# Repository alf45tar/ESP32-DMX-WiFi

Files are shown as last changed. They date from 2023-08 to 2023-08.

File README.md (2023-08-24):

# ESP32-DMX-WiFi

Art-Net to DMX gateway and viceversa. It supports RDM and sACN (E1.31) too.

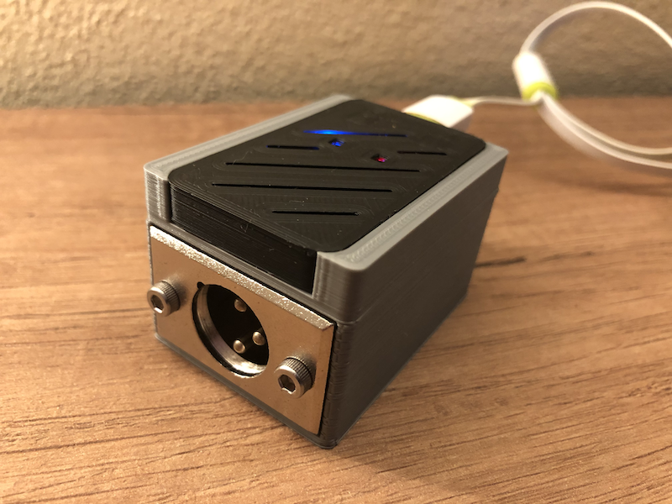
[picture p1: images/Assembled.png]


Strongly based on amazing [LXDMXWiFi_Library](https://github.com/claudeheintz/LXDMXWiFi_Library) example [ESP32-DMX_rdm](https://github.com/claudeheintz/LXDMXWiFi_Library/tree/master/examples/ESP32-DMX_rdm).

Configuration utility for macOS and Windows is [here](https://github.com/claudeheintz/LXDMXWiFi_Library/tree/master/examples/configuration%20utility)

Changes from original source are:
```
#define STARTUP_MODE_PIN       0    // use onboard built-in button for force default setup
#define DIRECTION_PIN          4    // pin for output direction enable on RS-485 transceiver chip
#define DMXSERIAL_INPUT_PIN   16    // default UART2 RX pin
#define DMXSERIAL_OUTPUT_PIN  17    // default UART2 TX pin
#define STATUS_LED             2    // LED_BUILTIN for DOIT ESP32 DevKit V1

....

#define USE_REMOTE_CONFIG      0    // uncommented line for enable the configuration utility
```

## Bill of materials

- DOIT ESP32 DevKit V1 30 pins board
- RS-485 transceiver like SN75176 or MAX485 or equivalent
- Male XLR panel mount connector
- 2x M3 x 8 mm bolts
- 2x M3 nuts
- 1K Ohm 1/4 watt resistor
- 2K Ohm 1/4 watt resistor

## Schematic

```

RX2/GPIO16  ---+
               |                       
          2k   |   1k    +---------------+
GND  ---/\/\/\-+-/\/\/\--| R         VCC |---------- +5V (VIN when ESP32 board is powered by USB)
                         |               |
                    +----| RE/         B |---------- Data - (XLR pin 2)
                    |    |    SN75176    |
GPIO04      --------+----| DE          A |---------- Data + (XLR pin 3)
                         |               |
TX2/GPIO17  -------------| D         GND |---+------ Ground (XLR pin 1)
                         +---------------+   |
                                             |
                                            GND
```

## Images

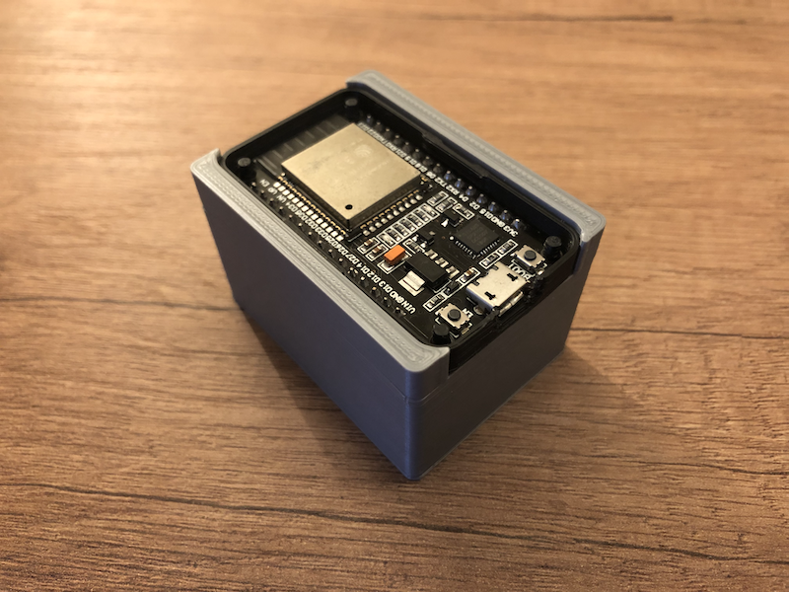
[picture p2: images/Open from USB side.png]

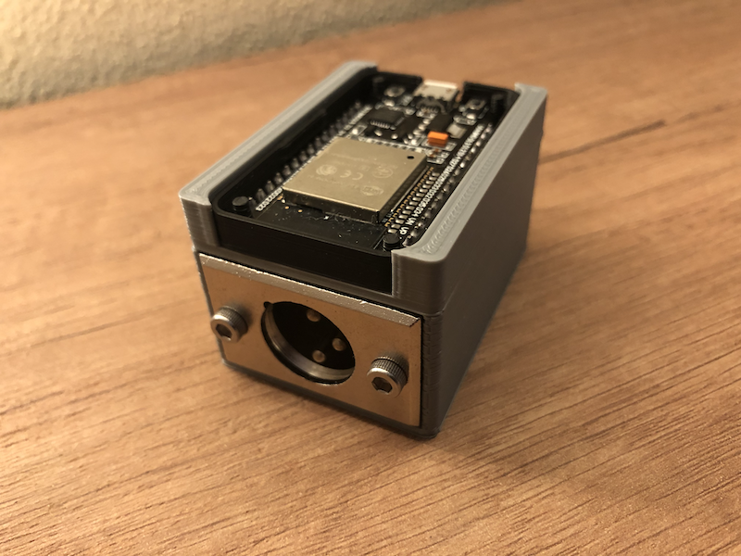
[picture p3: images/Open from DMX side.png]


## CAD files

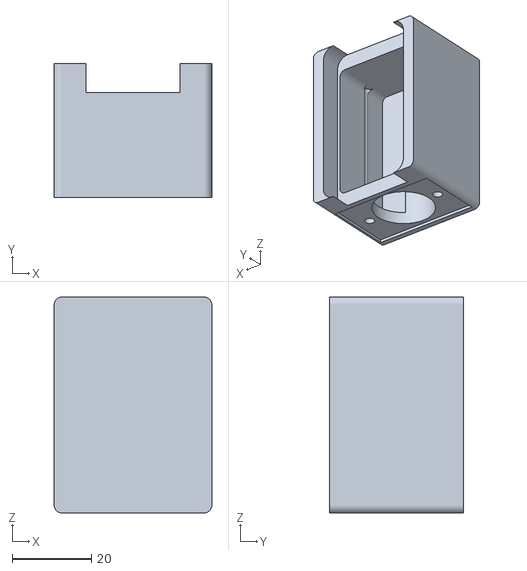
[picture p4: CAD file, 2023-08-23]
DMX Enclosure.stl
39.8 x 33.8 x 54.5

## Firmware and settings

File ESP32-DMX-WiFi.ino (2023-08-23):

/**************************************************************************/
/*
    @file     ESP32-DMX.ino
    @author   Claude Heintz
    @license  BSD (see LXDMXWiFi.h)
    @copyright 2017-2018 by Claude Heintz All Rights Reserved

    Example using LXDMXWiFi_Library for output of Art-Net or E1.31 sACN from
    ESP32 WiFi connection to serial DMX.  Or, input from DMX to the network.
    Allows remote configuration of WiFi connection and protocol settings.

    Art-Net(TM) Designed by and Copyright Artistic Licence Holdings Ltd.
    sACN E 1.31 is a public standard published by the PLASA technical standards program

    Note:  This example requires the LXESP32DMX library for DMX serial output
           https://github.com/claudeheintz/LXESP32DMX

    @section  HISTORY

    v1.0 - First release
    v1.1 - Improve multi-task compatibility
    v1.2 - Modified for Adafruit ESP-32 Feather
    v1.3 - adds ArtPoll response in input mode
	v1.4 - add variable tx/rx pin assignments

*/
/**************************************************************************/

#include <LXESP32DMX.h>
#include <UID.h>
#include <TOD.h>
#include <rdm_utility.h>
#include <WiFi.h>
#include <WiFiUdp.h>
#include "LXDMXWiFi.h"
#include <LXWiFiArtNet.h>
#include <LXWiFiSACN.h>
#include "LXDMXWiFiConfig.h"
#include "freertos/task.h"


#define STARTUP_MODE_PIN       0    // pin for force default setup when low (use 10k pullup to insure high)

#define DIRECTION_PIN			     4		// pin for output direction enable on MAX481 chip
#define DMXSERIAL_INPUT_PIN		16		// default UART2 RX pin
#define DMXSERIAL_OUTPUT_PIN	17		// default UART2 TX pin
#define STATUS_LED             2    // LED_BUILTIN for DOIT ESP32 DevKit V1

#define DEBUG_PIN_A 22
#define DEBUG_PIN_B 23
#define DEBUG_PIN_C 15

char ssid[32];
char password[32];

// RDM defines
#define DISC_STATE_SEARCH 0
#define DISC_STATE_TBL_CK 1
/*
   If RDM_DISCOVER_ALWAYS == 0, the times RDM discovery runs is limited to 10 cycles
   of table check and search.  When rdm_discovery_enable reaches zero, continous RDM
   discovery stops.  Other ArtRDM packets continue to be relayed.
   If an Art-Net TODRequest or TODControl packet is received, the rdm_discovery_enable
   counter is reset and discovery runs again until rdm_discovery_enable reaches zero.
*/
#define RDM_DISCOVER_ALWAYS 0

/*         
 *  To allow use of the configuration utility, uncomment the following to define USE_REMOTE_CONFIG
 *  When using remote configuration:
 *        The remote configuration utility can be used to edit the settings without re-loading the sketch.
 *        Settings from persistent memory are used unless the startup pin is read LOW.
 *        Holding the startup pin low temporarily uses the settings in the LXDMXWiFiConfig.initConfig() method.
 *        This insures there is a default way of connecting to the sketch in order to use the remote utility,
 *        even if it is configured to use a WiFi network that is unavailable.
 *
 *	Without remote configuration (USE_REMOTE_CONFIG remains undefined), settings are read from the 
 *  LXDMXWiFiConfig.initConfig() method.  So, it is necessary to edit that function in order to change
 *  the settings.
 */
 #define USE_REMOTE_CONFIG 0

// dmx protocol interfaces for parsing packets (created in setup)
LXWiFiArtNet* artNetInterface;
LXWiFiSACN*   sACNInterface;

// EthernetUDP instances to let us send and receive UDP packets
WiFiUDP aUDP;
WiFiUDP sUDP;

// the following appear to be ESP32's default AP address/subnet mask
// required to specify as WiFi.localIP() returns 0.0.0.0 when in AP mode and must use softAPIP() instead
IPAddress local_ip_address = IPAddress(192,168,4,1);
IPAddress local_subnet_mask = IPAddress(255,255,255,0);

// direction output from network/input to network
uint8_t dmx_direction = 0;

// Output mode: received packet contained dmx
int art_packet_result = 0;
int acn_packet_result = 0;

// Input mode:  received slots when inputting dmx to network
int got_dmx = 0;

// RDM globals
uint8_t rdm_enabled = 0;                      // global RDM flag
uint8_t rdm_discovery_enable = 10;            // limit RDM discovery which can cause flicker in some equipment
uint8_t discovery_state = DISC_STATE_TBL_CK;  // alternates between checking the TOD and discovery search
uint8_t discovery_tbl_ck_index = 0;           // next entry in table to check by sending DISC_MUTE
uint8_t tableChangedFlag = 0;                 // set when TOD is changed by device added or removed
uint8_t idle_count = 0;                       // count to determine cycles devoted to RDM discovery
TOD tableOfDevices;                           // UUIDs of found devices
TOD discoveryTree;                            // stack of UUID ranges for discovery search

UID lower(0, 0, 0, 0, 0, 0);
UID upper(0, 0, 0, 0, 0, 0);
UID mid(0, 0, 0, 0, 0, 0);
UID found(0, 0, 0, 0, 0, 0);

// used to toggle indicator LED on and off
uint8_t led_state = 0;

/*
   utility function to toggle indicator LED on/off
*/
void blinkLED() {
  if ( led_state ) {
    digitalWrite(STATUS_LED, HIGH);
    led_state = 0;
  } else {
    digitalWrite(STATUS_LED, LOW);
    led_state = 1;
  }
}

/*
   artAddress callback allows storing of config information
   artAddress may or may not have set this information
   but relevant fields are copied to config struct and stored to EEPROM
*/
void artAddressReceived() {
  DMXWiFiConfig.setArtNetPortAddress( artNetInterface->universe() );
  DMXWiFiConfig.setNodeName( artNetInterface->longName() );
  DMXWiFiConfig.commitToPersistentStore();
}

void artTodRequestReceived(uint8_t* pdata) {
  rdm_discovery_enable = 10;
  artNetInterface->send_art_tod(&aUDP, tableOfDevices.rawBytes(), tableOfDevices.count());
}

void artRDMReceived(uint8_t* pdata) {
  uint8_t plen = pdata[1] + 2;
  uint8_t j;

  //copy into ESP32DMX outgoing packet
  uint8_t* pkt = ESP32DMX.rdmData();
  for (j = 0; j < plen; j++) {
    pkt[j + 1] = pdata[j];
  }
  pkt[0] = 0xCC;


  if ( ESP32DMX.sendRDMControllerPacket() ) {
    artNetInterface->send_art_rdm(&aUDP, ESP32DMX.receivedRDMData(), aUDP.remoteIP());
  }
}

/*
   artIpProg callback allows storing of config information
   cmd field bit 7 indicates that settings should be programmed
*/
void artIpProgReceived(uint8_t cmd, IPAddress addr, IPAddress subnet) {
  if ( cmd & 0x80 ) {
    if ( cmd & 0x40 ) {	//enable dhcp, other fields not written
      if ( DMXWiFiConfig.staticIPAddress() ) {
        DMXWiFiConfig.setStaticIPAddress(0);
      } else {
        return;	// already set to dhcp
      }
    } else {
      if ( ! DMXWiFiConfig.staticIPAddress() ) {
        DMXWiFiConfig.setStaticIPAddress(1);	// static not dhcp
      }
      if ( cmd & 0x08 ) {	//factory reset
        DMXWiFiConfig.initConfig();
      } else {
        if ( cmd & 0x04 ) {	//programIP
          DMXWiFiConfig.setStationIPAddress(addr);
        }
        if ( cmd & 0x02 ) {	//programSubnet
          DMXWiFiConfig.setStationSubnetMask(subnet);
        }
      }
    }	// else ( ! dhcp )

    DMXWiFiConfig.commitToPersistentStore();
  }
}

/*
  Indicator was requested by ArtAddress packet
*/
void artIndicatorReceived(bool normal, bool mute, bool locate) {
    if (normal) {
        Serial.println("Normal mode");
    } else if (mute) {
        Serial.println("Mute mode");
    } else if (locate) {
        Serial.println("Locate mode");
    }
}

/*
  DMX input callback function sets number of slots received by ESP32DMX
*/

void gotDMXCallback(int slots) {
  got_dmx = slots;
}

/************************************************************************/

uint8_t testMute(UID u) {
  // try three times to get response when sending a mute message
  if ( ESP32DMX.sendRDMDiscoveryMute(u, RDM_DISC_MUTE) ) {
    return 1;
  }
  if ( ESP32DMX.sendRDMDiscoveryMute(u, RDM_DISC_MUTE) ) {
    return 1;
  }
  if ( ESP32DMX.sendRDMDiscoveryMute(u, RDM_DISC_MUTE) ) {
    return 1;
  }
  return 0;
}

void checkDeviceFound(UID found) {
  if ( testMute(found) ) {
    tableOfDevices.add(found);
    tableChangedFlag = 1;
  }
}

uint8_t checkTable(uint8_t ck_index) {
  if ( ck_index == 0 ) {
    ESP32DMX.sendRDMDiscoveryMute(BROADCAST_ALL_DEVICES_ID, RDM_DISC_UNMUTE);
  }

  if ( tableOfDevices.getUIDAt(ck_index, &found) )  {
    if ( testMute(found) ) {
      // device confirmed
      return ck_index += 6;
    }

    // device not found
    tableOfDevices.removeUIDAt(ck_index);
    tableChangedFlag = 1;
    return ck_index;
  }
  // index invalid
  return 0;
}

//called when range responded, so divide into sub ranges push them on stack to be further checked
void pushActiveBranch(UID lower, UID upper) {
  if ( mid.becomeMidpoint(lower, upper) ) {
    discoveryTree.push(lower);
    discoveryTree.push(mid);
    discoveryTree.push(mid);
    discoveryTree.push(upper);
  } else {
    // No midpoint possible:  lower and upper are equal or a 1 apart
    checkDeviceFound(lower);
    checkDeviceFound(upper);
  }
}

void pushInitialBranch() {
  lower.setBytes(0);
  upper.setBytes(BROADCAST_ALL_DEVICES_ID);
  discoveryTree.push(lower);
  discoveryTree.push(upper);

  //ETC devices seem to only respond with wildcard or exact manufacturer ID
  lower.setBytes(0x657400000000);
  upper.setBytes(0x6574FFFFFFFF);
  discoveryTree.push(lower);
  discoveryTree.push(upper);
}

uint8_t checkNextRange() {
  if ( discoveryTree.pop(&upper) ) {
    if ( discoveryTree.pop(&lower) ) {
      if ( lower == upper ) {
        checkDeviceFound(lower);
      } else {        //not leaf so, check range lower->upper
        uint8_t result = ESP32DMX.sendRDMDiscoveryPacket(lower, upper, &found);
        if ( result ) {
          //this range responded, so divide into sub ranges push them on stack to be further checked
          pushActiveBranch(lower, upper);

        } else if ( ESP32DMX.sendRDMDiscoveryPacket(lower, upper, &found) ) {
          pushActiveBranch(lower, upper); //if discovery fails, try a second time
        }
      }         // end check range
      return 1; // UID ranges may be remaining to test
    }           // end valid pop
  }             // end valid pop
  return 0;     // none left to pop
}

void sendTODifChanged() {
  if ( tableChangedFlag ) {   //if the table has changed...
    tableChangedFlag--;

    artNetInterface->send_art_tod(&aUDP, tableOfDevices.rawBytes(), tableOfDevices.count());

    Serial.println("_______________ Table Of Devices _______________");
    tableOfDevices.printTOD();
  }
}

void updateRDMDiscovery() {
  if ( rdm_discovery_enable ) {  // run RDM updates for a limited number of times
    if ( discovery_state ) {
      // check the table of devices
      discovery_tbl_ck_index = checkTable(discovery_tbl_ck_index);

      if ( discovery_tbl_ck_index == 0 ) {
        // done with table check
        discovery_state = DISC_STATE_SEARCH;
        pushInitialBranch();

        sendTODifChanged();
      } //end table check ended
    } else {    // search for devices in range popped from discoveryTree

      if ( checkNextRange() == 0 ) {
        // done with search
        discovery_tbl_ck_index = 0;
        discovery_state = DISC_STATE_TBL_CK;

        sendTODifChanged();
        if ( RDM_DISCOVER_ALWAYS == 0 ) {
          rdm_discovery_enable--;
        }
      }
    }           //end search
  }             // discovery enabled
}
/************************************************************************

  Setup creates the WiFi connection.

  It also creates the network protocol object,
  either an instance of LXWiFiArtNet or LXWiFiSACN.

  if OUTPUT_FROM_NETWORK_MODE:
     Starts listening on the appropriate UDP port.

     And, it starts the ESP32DMX sending serial DMX via the UART1 TX pin.
     (see the LXESP32DMX library documentation for driver details)

   if INPUT_TO_NETWORK_MODE:
     Starts ESP32DMX listening for DMX ( received as serial on UART0 RX pin. )

*************************************************************************/

void setup() {
  Serial.begin(115200);
  //Serial.setDebugOutput(1); //use uart0 for debugging
  pinMode(STATUS_LED, OUTPUT);
  pinMode(STARTUP_MODE_PIN, INPUT_PULLUP);
  pinMode(DIRECTION_PIN, OUTPUT);
  
  //debugging
  pinMode(DEBUG_PIN_A, OUTPUT);
  pinMode(DEBUG_PIN_B, OUTPUT);
  pinMode(DEBUG_PIN_C, OUTPUT);

  uint8_t bootStatus = DMXWiFiConfig.begin(1);//aparently need to read from persistent to be able to write to it
  uint8_t dhcpStatus = 0;                     //hence, read in begin and replace below if startup pin is low

#ifdef USE_REMOTE_CONFIG
  if ( digitalRead(STARTUP_MODE_PIN) == 0 ) {
#else
  if ( true ) {
#endif
    DMXWiFiConfig.initConfig();
    Serial.println("default startup config ");
  } else {
    Serial.println("using stored config ");
  }

  dmx_direction = DMXWiFiConfig.inputToNetworkMode();
  rdm_enabled   = DMXWiFiConfig.rdmMode();

  if ( DMXWiFiConfig.APMode() ) {            // WiFi startup
    Serial.print("AP_MODE ");
    Serial.print(DMXWiFiConfig.SSID());
    WiFi.mode(WIFI_AP);
    WiFi.softAP(DMXWiFiConfig.SSID());
    

    if ( digitalRead(STARTUP_MODE_PIN) != 0 ) { 
      WiFi.softAPConfig(DMXWiFiConfig.apIPAddress(), DMXWiFiConfig.apGateway(), DMXWiFiConfig.apSubnet());
      local_subnet_mask = DMXWiFiConfig.apSubnet();
    } else {
      Serial.print(" default AP settings ");
      Serial.println(DMXWiFiConfig.nodeName());
    };

    local_ip_address = WiFi.softAPIP();

    Serial.print(" accessPoint SSID ");
    Serial.print(DMXWiFiConfig.SSID());

    Serial.print(", ");
  } else {
    Serial.print("wifi connecting to ");
    Serial.print(DMXWiFiConfig.SSID());
    Serial.print("... ");
    WiFi.mode(WIFI_STA);
    strcpy(ssid, DMXWiFiConfig.SSID());
    strcpy(password, DMXWiFiConfig.password());
    WiFi.begin((const char*)ssid, (const char*)password);

    // static IP otherwise uses DHCP
    if ( DMXWiFiConfig.staticIPAddress() ) {
      Serial.print("static IP");
      WiFi.config(DMXWiFiConfig.stationIPAddress(), DMXWiFiConfig.stationGateway(), DMXWiFiConfig.stationSubnet());
    } else {
      dhcpStatus = 1;
    }

    while (WiFi.status() != WL_CONNECTED)  {
      delay(100);
      blinkLED();
    }

    local_ip_address = WiFi.localIP();
    local_subnet_mask = WiFi.subnetMask();
  }
  Serial.print("wifi started: ");
  Serial.println(local_ip_address);

  //------------------- Initialize serialDMX  -------------------

  if ( dmx_direction == OUTPUT_FROM_NETWORK_MODE ) {                // DMX Driver startup based on direction flag
    Serial.println("starting DMX");
    ESP32DMX.startRDM(DIRECTION_PIN, DMXSERIAL_INPUT_PIN, DMXSERIAL_OUTPUT_PIN);
  } else {
    Serial.println("starting DMX input");
    ESP32DMX.setDirectionPin(DIRECTION_PIN);
    ESP32DMX.setDataReceivedCallback(&gotDMXCallback);
    ESP32DMX.startInput(DMXSERIAL_INPUT_PIN);
  }

  //------------------- Initialize network<->DMX interfaces -------------------

  sACNInterface = new LXWiFiSACN();
  sACNInterface->setUniverse(DMXWiFiConfig.sACNUniverse());

  artNetInterface = new LXWiFiArtNet(local_ip_address, local_subnet_mask);
  artNetInterface->setUniverse(DMXWiFiConfig.artnetPortAddress());	//setUniverse for LXArtNet class sets complete Port-Address
  artNetInterface->setArtAddressReceivedCallback(&artAddressReceived);
  artNetInterface->setArtIpProgReceivedCallback(&artIpProgReceived);
  artNetInterface->setArtTodRequestCallback(&artTodRequestReceived);
  artNetInterface->setArtRDMCallback(&artRDMReceived);
  artNetInterface->setArtIndicatorReceivedCallback(&artIndicatorReceived);
  char* nn = DMXWiFiConfig.nodeName();
  if ( nn[0] != 0 ) {
    strcpy(artNetInterface->longName(), nn);
  }
  artNetInterface->setStatus2Flag(ARTNET_STATUS2_SACN_CAPABLE, 1);
  artNetInterface->setStatus2Flag(ARTNET_STATUS2_DHCP_CAPABLE, 1);
  if ( dhcpStatus ) {
    artNetInterface->setStatus2Flag(ARTNET_STATUS2_DHCP_USED, 1);
  }
  if ( bootStatus ) {
    artNetInterface->setStatus1Flag(ARTNET_STATUS1_FACTORY_BOOT, 1);
  }
  if ( rdm_enabled ) {
    artNetInterface->setStatus1Flag(ARTNET_STATUS1_RDM_CAPABLE, 1);
  }
  artNetInterface->setStatus1Flag(ARTNET_STATUS1_RDM_CAPABLE, 1);
  Serial.print("interfaces created, ");

  // if output from network, start wUDP listening for packets
  if ( dmx_direction == OUTPUT_FROM_NETWORK_MODE ) {
    if ( DMXWiFiConfig.multicastMode() ) {
      if ( DMXWiFiConfig.APMode() ) {
        sUDP.beginMulticast(DMXWiFiConfig.multicastAddress(), sACNInterface->dmxPort());  //WiFi.softAPIP(),
      } else {
        sUDP.beginMulticast(DMXWiFiConfig.multicastAddress(), sACNInterface->dmxPort());  //WiFi.localIP(),
      }
    } else {
      sUDP.begin(sACNInterface->dmxPort());
    }
    aUDP.begin(artNetInterface->dmxPort());
    artNetInterface->send_art_poll_reply(&aUDP, ARTPOLL_OUTPUT_MODE);
    Serial.print("udp started listening,");
  } else {
    aUDP.begin(artNetInterface->dmxPort());
    artNetInterface->send_art_poll_reply(&aUDP, ARTPOLL_INPUT_MODE);
  }
  
  

  Serial.println(" setup complete.");
  blinkLED();


  // increase the priority of this task (main.cpp sets it at 1);
  vTaskPrioritySet(xTaskGetCurrentTaskHandle(), 2);
  
  Serial.print("number of tasks is ");
  Serial.println(uxTaskGetNumberOfTasks());
  /*
  char taskinfo[256];
  TaskStatus_t tslist[10];
  uint32_t trt;
  uxTaskGetSystemState(tslist, 10, &trt);
  //vTaskList(taskinfo);
  //Serial.println(taskinfo);*/

} //setup

/************************************************************************

  Copy to output merges slots for Art-Net and sACN on HTP basis

*************************************************************************/

void copyDMXToOutput(void) {
  uint8_t a, s;
  uint16_t a_slots = artNetInterface->numberOfSlots();
  uint16_t s_slots = sACNInterface->numberOfSlots();
  xSemaphoreTake( ESP32DMX.lxDataLock, portMAX_DELAY );
  for (int i = 1; i <= DMX_UNIVERSE_SIZE; i++) {
    if ( i <= a_slots ) {
      a = artNetInterface->getSlot(i);
    } else {
      a = 0;
    }
    if ( i <= s_slots ) {
      s = sACNInterface->getSlot(i);
    } else {
      s = 0;
    }
    if ( a > s ) {
      ESP32DMX.setSlot(i , a);
    } else {
      ESP32DMX.setSlot(i , s);
    }
  }
  ESP32DMX.setMaxSlots(512);
  xSemaphoreGive( ESP32DMX.lxDataLock );
}

/************************************************************************

  Checks to see if packet is a config packet.

     In the case it is a query, it replies with the current config from persistent storage.

     In the case of upload, it copies the payload to persistent storage
     and also replies with the config settings.

*************************************************************************/

void checkConfigReceived(LXDMXWiFi* interface, WiFiUDP* cUDP) {
  if ( strcmp(CONFIG_PACKET_IDENT, (const char *) interface->packetBuffer()) == 0 ) {	//match header to config packet
    Serial.print("config packet received, ");
    uint8_t reply = 0;
    if ( interface->packetBuffer()[8] == '?' ) {	//packet opcode is query
      DMXWiFiConfig.readFromPersistentStore();
      reply = 1;
    } else if (( interface->packetBuffer()[8] == '!' ) && (interface->packetSize() >= 171)) { //packet opcode is set
      Serial.println("upload packet");
      DMXWiFiConfig.copyConfig( interface->packetBuffer(), interface->packetSize());
      DMXWiFiConfig.commitToPersistentStore();
      reply = 1;
    } else if ( interface->packetBuffer()[8] == '^' ) {
      ESP.restart();
    } else {
      Serial.println("unknown config opcode.");
    }
    if ( reply) {
      DMXWiFiConfig.hidePassword();													// don't transmit password!
      cUDP->beginPacket(cUDP->remoteIP(), interface->dmxPort());				// unicast reply
      cUDP->write((uint8_t*)DMXWiFiConfig.config(), DMXWiFiConfigSIZE);
      cUDP->endPacket();
      Serial.println(DMXWiFiConfig.SSID());
      Serial.println("reply complete.");
      DMXWiFiConfig.restorePassword();
    }
    interface->packetBuffer()[0] = 0; //insure loop without recv doesn't re-trigger
    interface->packetBuffer()[1] = 0;
    blinkLED();
    delay(100);
    blinkLED();
    delay(100);
    blinkLED();
  }		// packet has config packet header
}

/************************************************************************

  Checks to see if the dmx callback indicates received dmx
     If so, send it using the selected interface.

*************************************************************************/
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
void loop() {
  //digitalWrite(DEBUG_PIN_C, LOW);
 
  if ( dmx_direction == OUTPUT_FROM_NETWORK_MODE ) {

    art_packet_result = artNetInterface->readDMXPacket(&aUDP);
    #ifdef USE_REMOTE_CONFIG
	if ( art_packet_result == RESULT_NONE ) {
		checkConfigReceived(artNetInterface, &aUDP);
	}
	#endif
    vTaskDelay(1);

    acn_packet_result = sACNInterface->readDMXPacket(&sUDP);
    #ifdef USE_REMOTE_CONFIG
	if ( acn_packet_result == RESULT_NONE ) {
		checkConfigReceived(sACNInterface, &sUDP);
	}
	#endif
    vTaskDelay(1);

    if ( (art_packet_result == RESULT_DMX_RECEIVED) || (acn_packet_result == RESULT_DMX_RECEIVED) ) {
      copyDMXToOutput();
      blinkLED();
    } else {
      // output was not updated last 5 times through loop so use a cycle to perform the next step of RDM discovery
      if ( rdm_enabled ) {
        idle_count++;
        if ( idle_count > 5 ) {
          updateRDMDiscovery();
          idle_count = 0;
        }
      }
    }

  } else {    //direction is input to network
    if ( DMXWiFiConfig.sACNMode() ) {
      checkInput(sACNInterface, &sUDP, DMXWiFiConfig.multicastMode());
    } else {
      if ( checkInput(artNetInterface, &aUDP, 0) == 0 ) {
        // if no dmx input, attempt to read from network (only handles ArtPoll, responding as input)
        art_packet_result = artNetInterface->readArtNetPacketInputMode(&aUDP);
        if ( art_packet_result == RESULT_NONE ) {
          checkConfigReceived(artNetInterface, &aUDP);
        }
      }
    }

  }
  //digitalWrite(DEBUG_PIN_C, HIGH);
  vTaskDelay(1);
  
}// loop()
